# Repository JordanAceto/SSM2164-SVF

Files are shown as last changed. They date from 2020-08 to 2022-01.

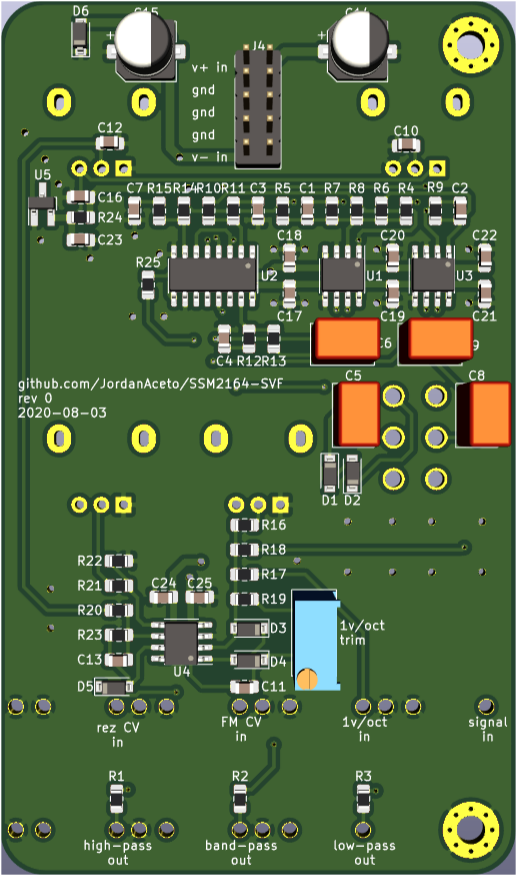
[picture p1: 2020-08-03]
main_pcb/pics/pcb_rear.png

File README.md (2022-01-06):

# SSI2164-SVF

State variable filter with audio and super-low-frequency modes.



---

## [SCHEMATIC](https://github.com/JordanAceto/SSI2164_SVF/blob/master/main_pcb/construction_docs/SSM2164_SVF_schematic.pdf)

---

Eurorack friendly pcb with mouting holes if flying wire construction is desired.

Range switch allows for super low frequency mode, which can be used as a sine wave LFO, or for creating "bouncy ADSRs", etc.

When used as a sine LFO, note that the band-pass and low-pass outputs are 90 &deg; out of phase with each other, and the high-pass and low-pass outputs are 180 &deg; out of phase. With a couple of inverters you can have 0 &deg;, 90 &deg;, 180 &deg;, and 270 &deg; outputs.

Note that the amplitude of the self oscillation is not perfectly flat across the frequency range, and may even peter out at very low frequencies. Additionally the sine wave appearing at the band-pass output is a little lower in amplitude than the other two. Don't expect amazing performance as a quadrature LFO, but I still find this to be a useful feature in a small system.

---

## Status of the project:

Task | Status |
---------|--------------|
Schematic capture | &#9745;
PCB layout | &#9745;
Test build | &#9745;
Safe to order boards| &#9745;

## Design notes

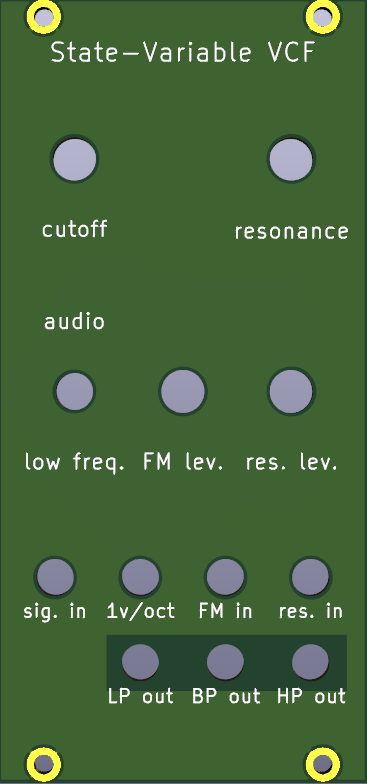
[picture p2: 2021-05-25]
front_panel/pics/front_panel.png

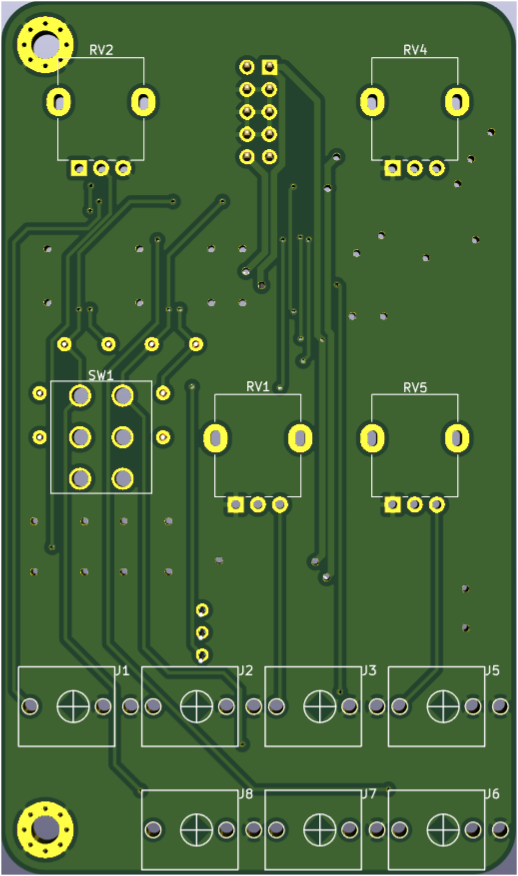
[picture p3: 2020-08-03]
main_pcb/pics/pcb_front.png

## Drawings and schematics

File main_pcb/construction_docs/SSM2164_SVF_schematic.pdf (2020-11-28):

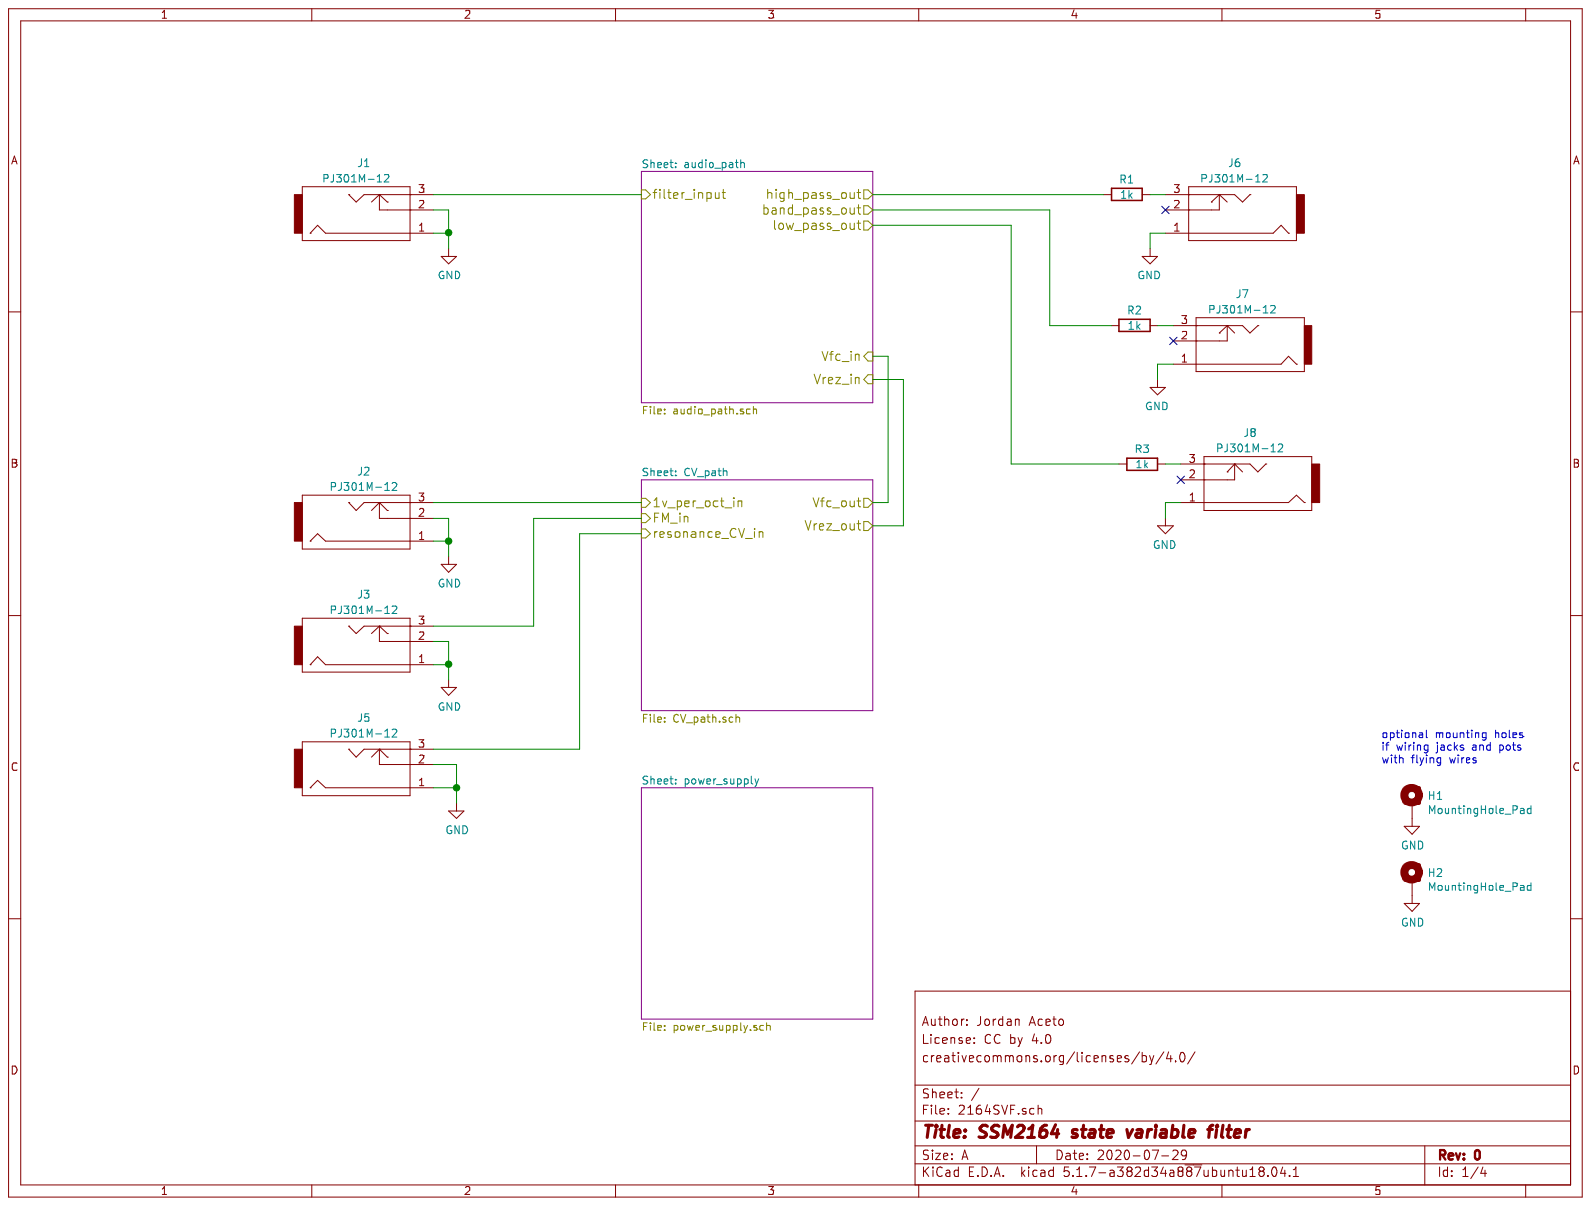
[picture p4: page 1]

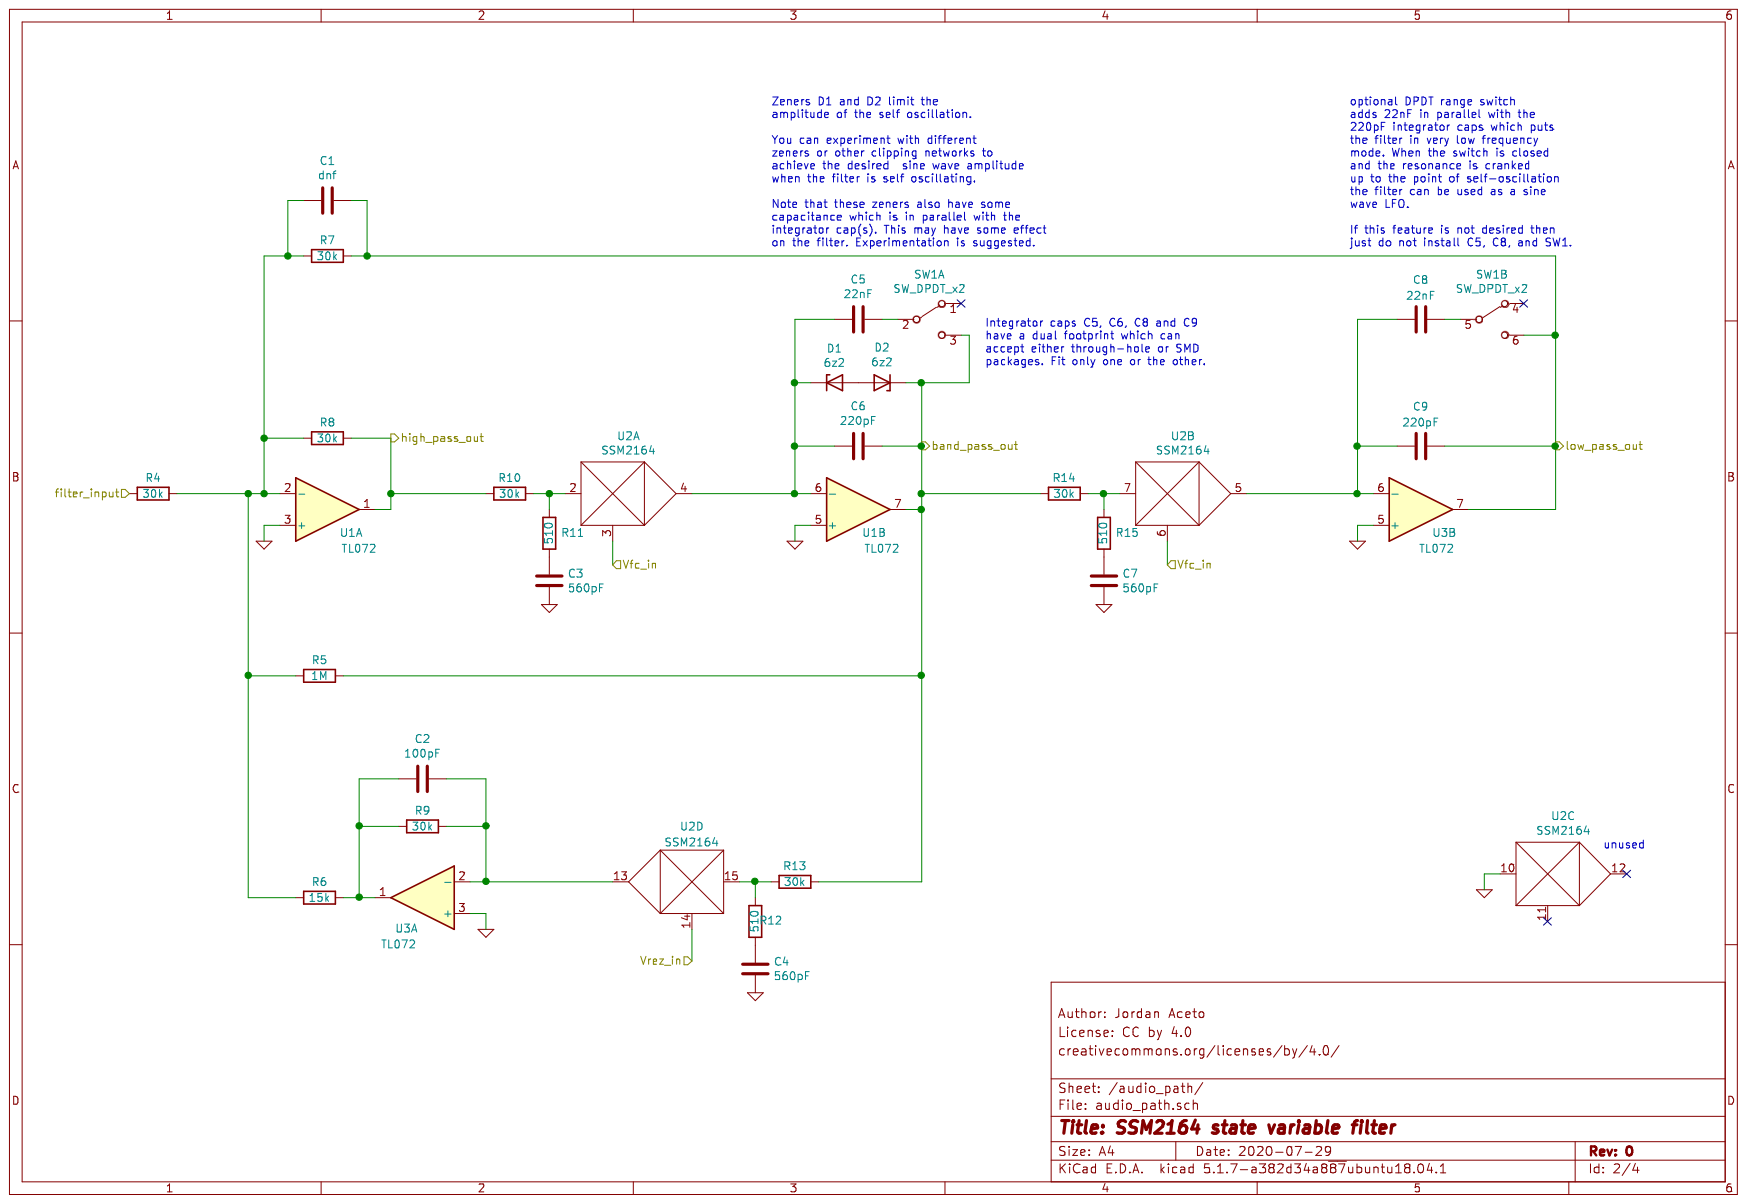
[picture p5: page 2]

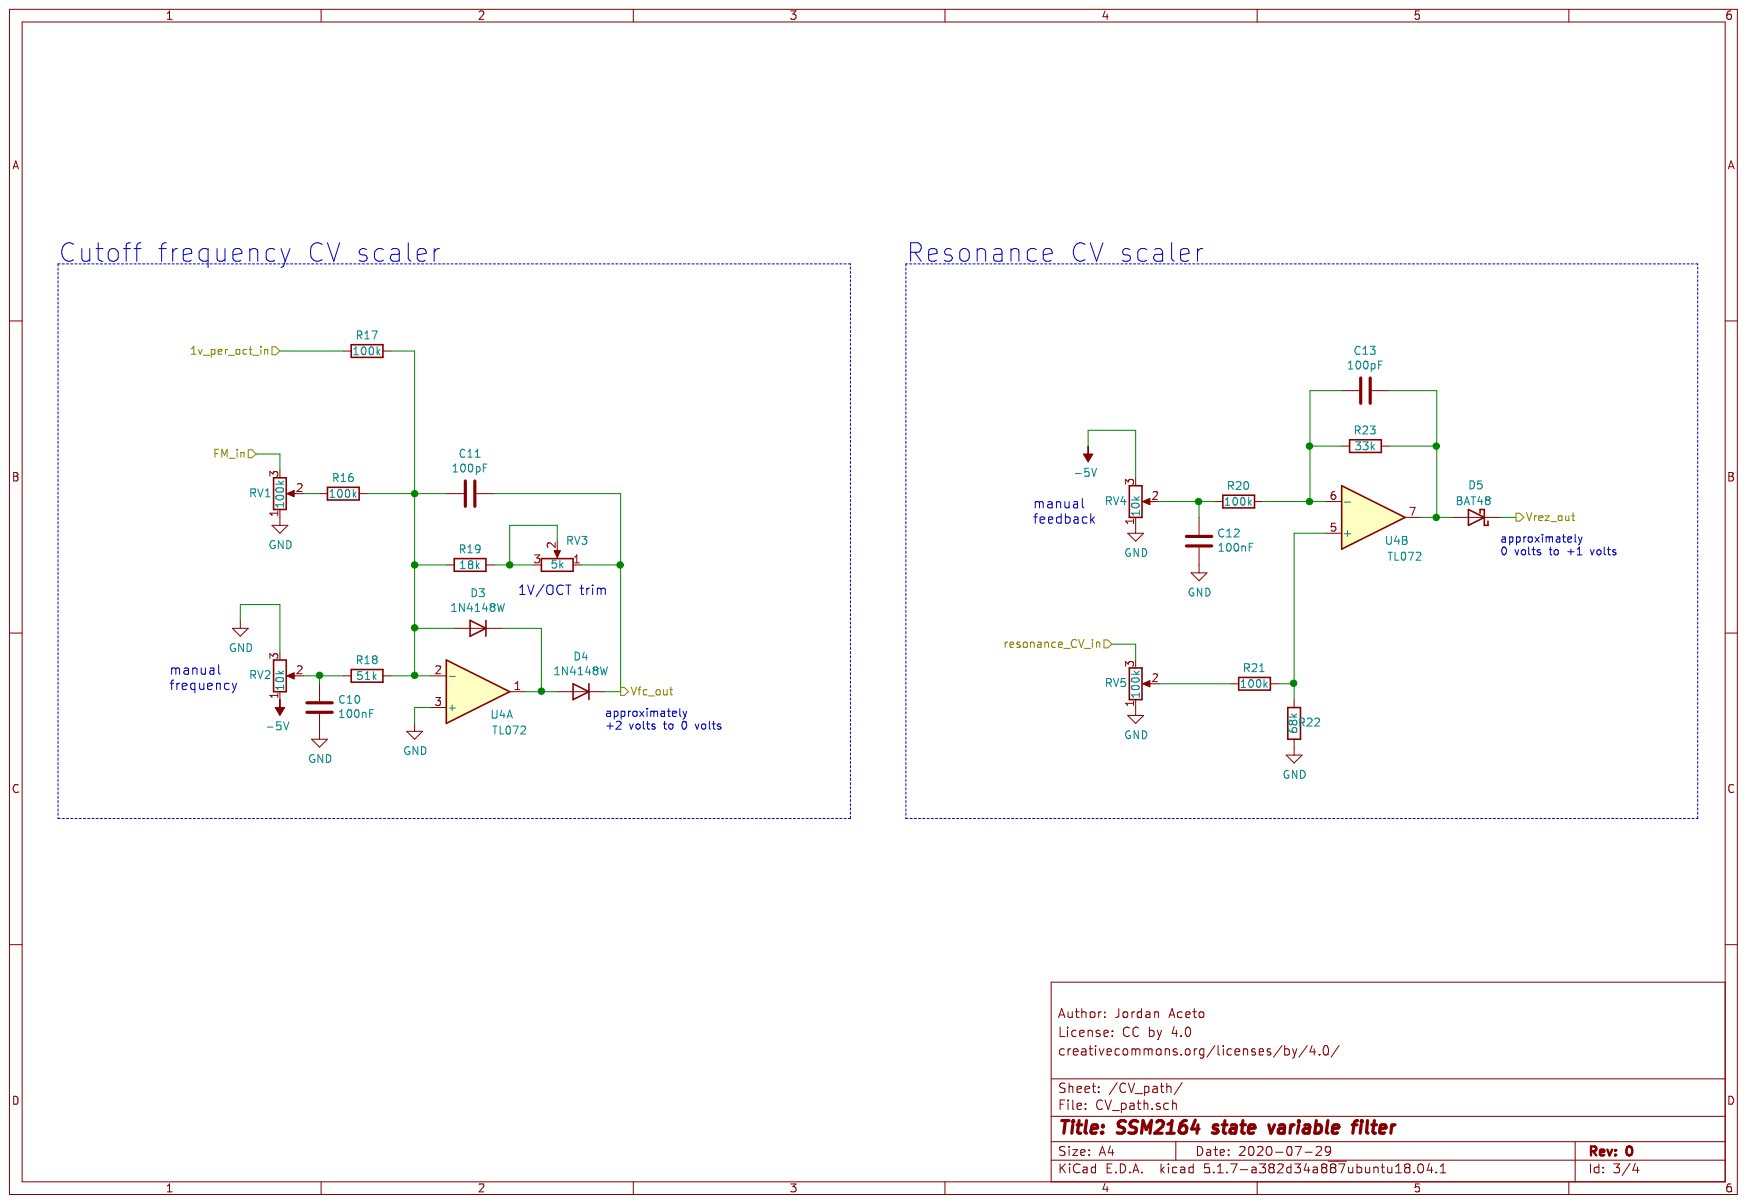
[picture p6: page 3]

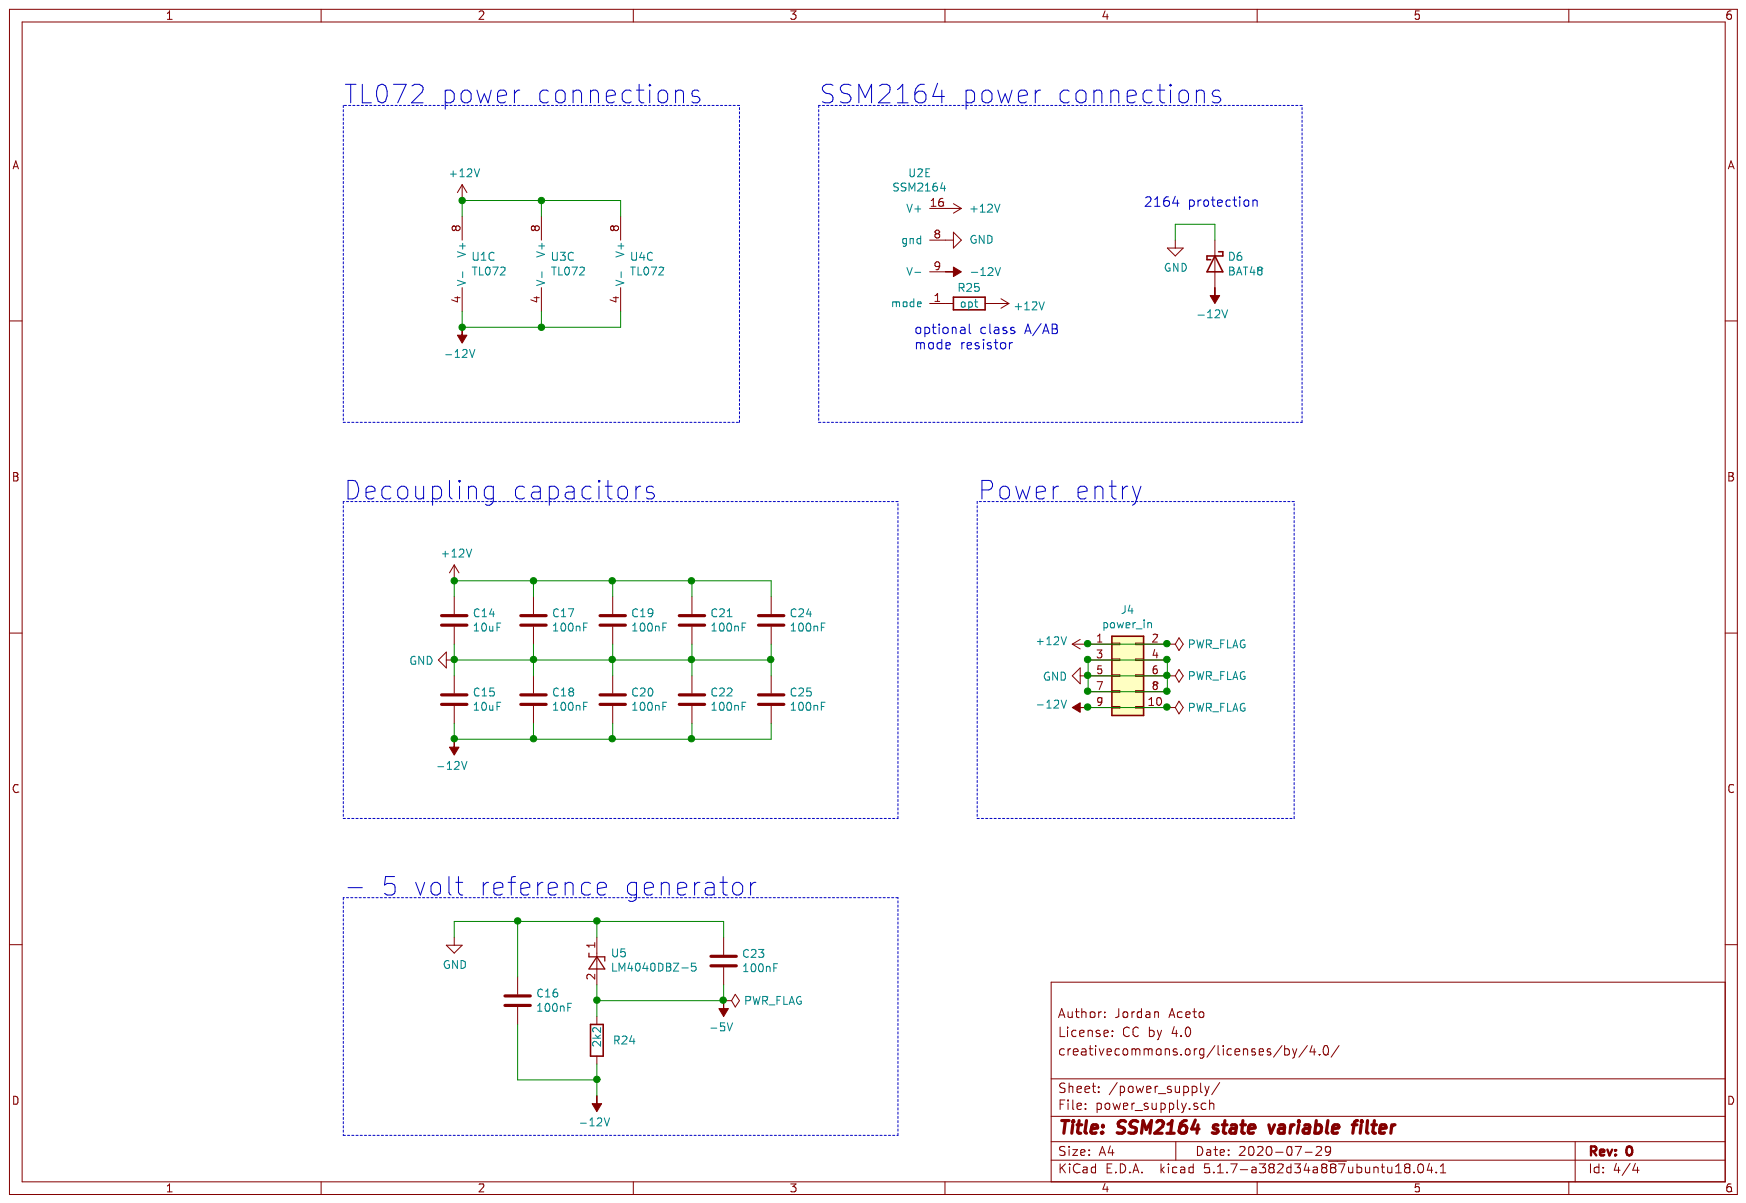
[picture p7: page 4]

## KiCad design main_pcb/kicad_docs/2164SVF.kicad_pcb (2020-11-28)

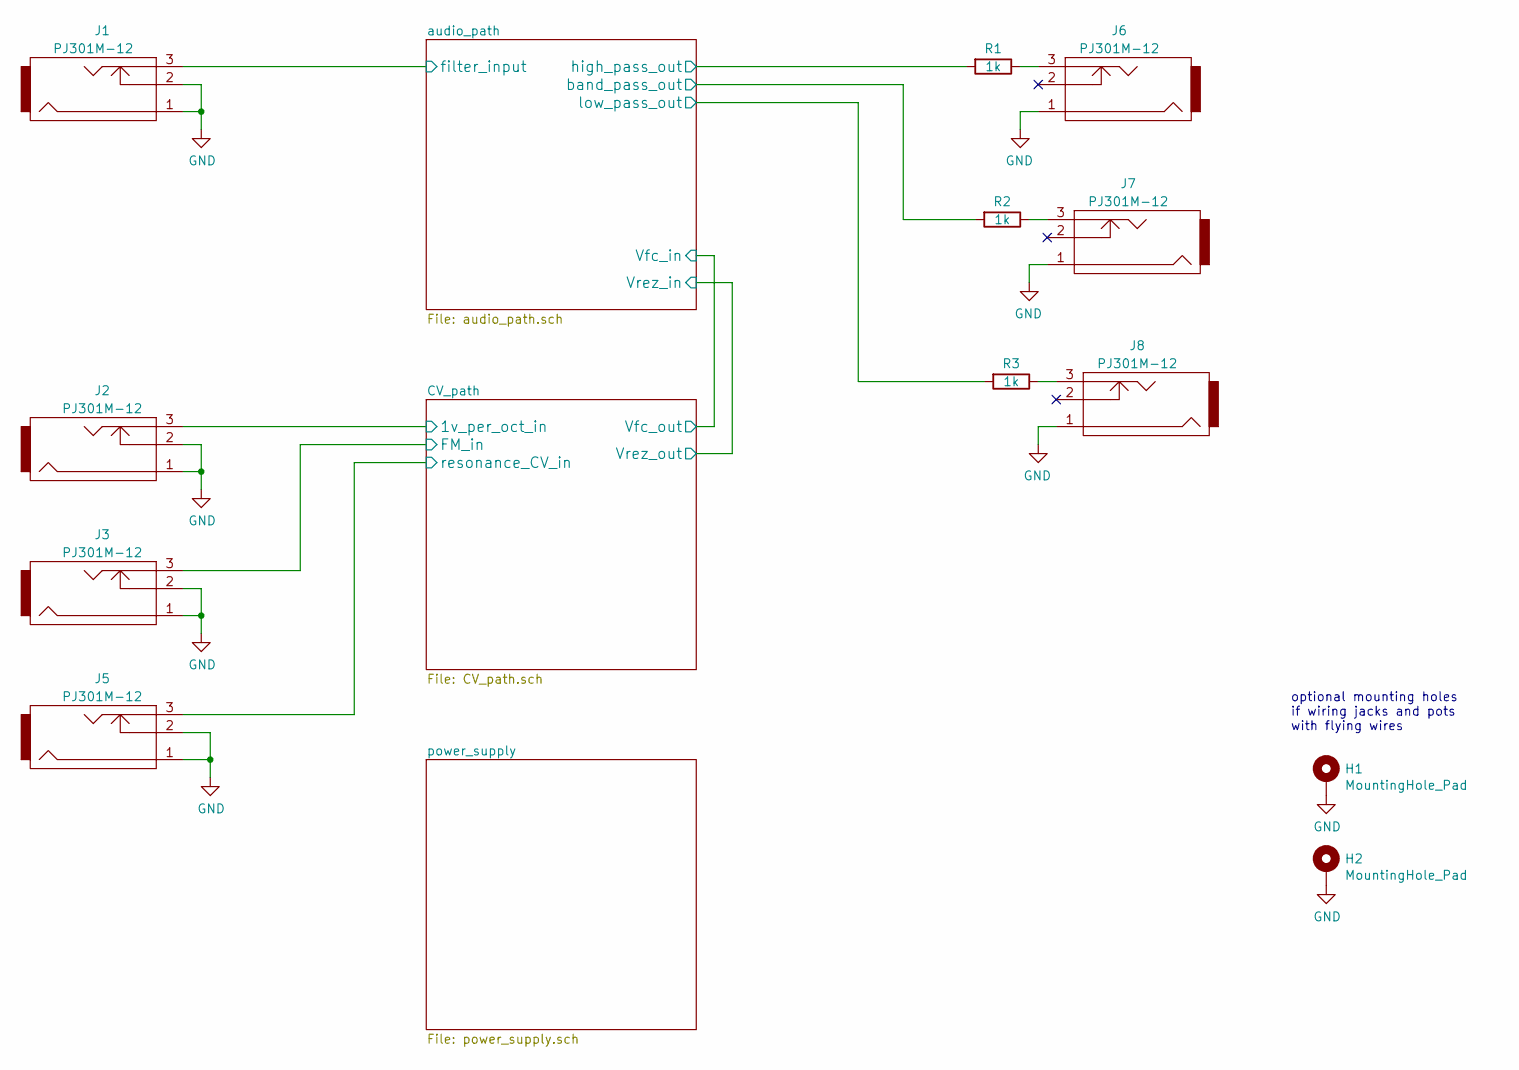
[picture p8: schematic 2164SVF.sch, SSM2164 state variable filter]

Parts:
H1, H2: MountingHole_Pad; MountingHole_3.2mm_M3_Pad_Via
J1, J2, J3, J5, J6, J7, J8: PJ301M-12
R1, R2, R3: 1k; R_0805_2012Metric_Pad1.15x1.40mm_HandSolder

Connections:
/CV_path/1v_per_oct_in: J2.3; also elsewhere on the board
/CV_path/FM_in: J3.3; also elsewhere on the board
/CV_path/resonance_CV_in: J5.3; also elsewhere on the board
/audio_path/band_pass_out: R2.2; also elsewhere on the board
/audio_path/filter_input: J1.3; also elsewhere on the board
/audio_path/high_pass_out: R1.2; also elsewhere on the board
/audio_path/low_pass_out: R3.2; also elsewhere on the board
GND: H1.1, H2.1, J1.1, J1.2, J2.1, J2.2, J3.1, J3.2, J5.1, J5.2, J6.1, J7.1, J8.1; also elsewhere on the board
unnamed: J6.3, R1.1
unnamed: J7.3, R2.1
unnamed: J8.3, R3.1

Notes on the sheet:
optional mounting holes if wiring jacks and pots with flying wires

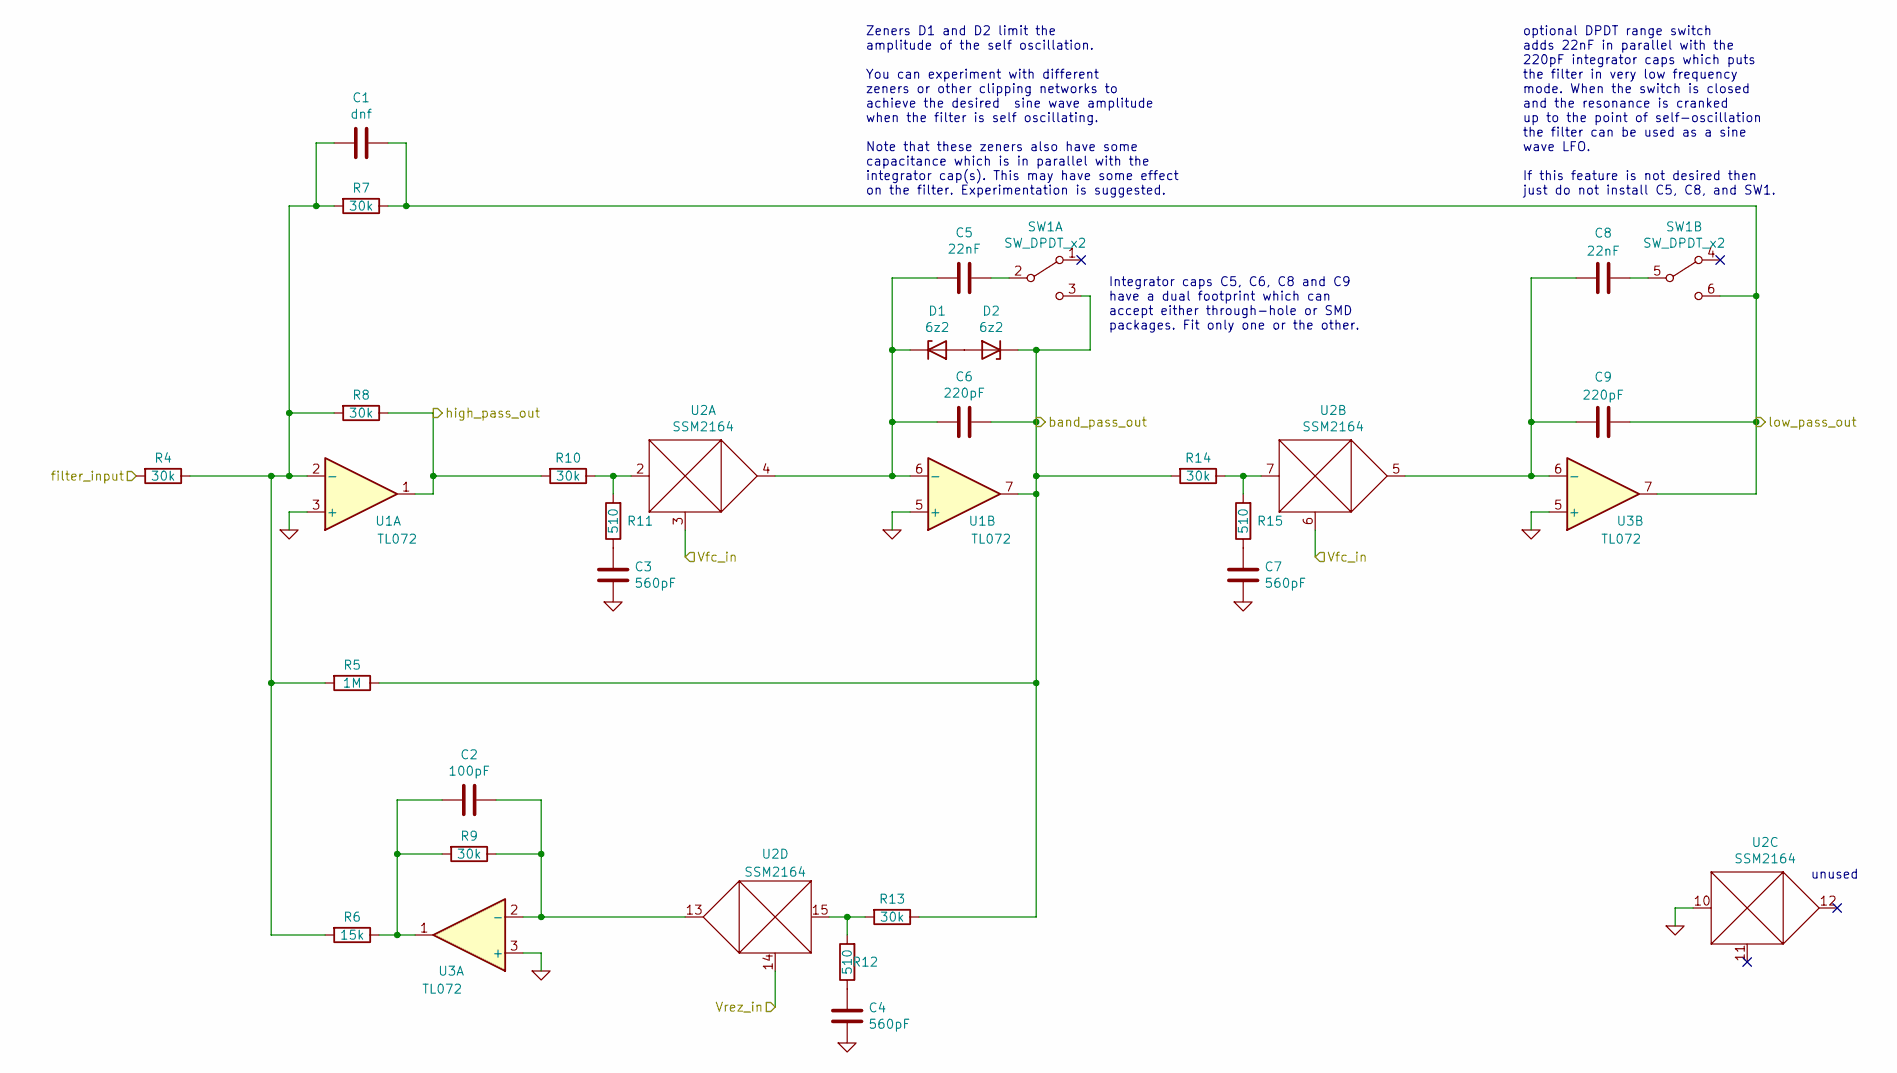
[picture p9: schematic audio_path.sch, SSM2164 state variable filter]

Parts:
C1: dnf; C_0805_2012Metric_Pad1.15x1.40mm_HandSolder
C2: 100pF; C_0805_2012Metric_Pad1.15x1.40mm_HandSolder
C3, C4, C7: 560pF; C_0805_2012Metric_Pad1.15x1.40mm_HandSolder
C5, C8: 22nF; timing_cap_dual_fp
C6, C9: 220pF; timing_cap_dual_fp
D1, D2: 6z2; D_SOD-123
R4, R7, R8, R9, R10, R13, R14: 30k; R_0805_2012Metric_Pad1.15x1.40mm_HandSolder
R5: 1M; R_0805_2012Metric_Pad1.15x1.40mm_HandSolder
R6: 15k; R_0805_2012Metric_Pad1.15x1.40mm_HandSolder
R11, R12, R15: 510; R_0805_2012Metric_Pad1.15x1.40mm_HandSolder
SW1: SW_DPDT_x2; DPDT_on_on
U1, U3: TL072; SOIC-8_3.9x4.9mm_P1.27mm
U2: SSM2164; SOIC-16_3.9x9.9mm_P1.27mm

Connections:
/audio_path/Vfc_in: U2.3, U2.6; also elsewhere on the board
/audio_path/Vrez_in: U2.14; also elsewhere on the board
/audio_path/band_pass_out: C6.1, D2.1 (K), R5.1, R13.1, R14.2, SW1.3 (C), U1.7; also elsewhere on the board
/audio_path/filter_input: R4.2; also elsewhere on the board
/audio_path/high_pass_out: R8.1, R10.2, U1.1; also elsewhere on the board
/audio_path/low_pass_out: C1.1, C9.1, R7.1, SW1.6 (C), U3.7; also elsewhere on the board
GND: C3.2, C4.2, C7.2, U1.3 (+), U1.5 (+), U2.10, U3.3 (+), U3.5 (+); also elsewhere on the board
unnamed: C1.2, R4.1, R5.2, R6.2, R7.2, R8.2, U1.2 (-)
unnamed: C2.1, R9.1, U2.13, U3.2 (-)
unnamed: C2.2, R6.1, R9.2, U3.1
unnamed: C3.1, R11.1
unnamed: C4.1, R12.1
unnamed: C5.1, SW1.2 (B)
unnamed: C5.2, C6.2, D1.1 (K), U1.6 (-), U2.4
unnamed: C7.1, R15.1
unnamed: C8.1, SW1.5 (B)
unnamed: C8.2, C9.2, U2.5, U3.6 (-)
unnamed: D1.2 (A), D2.2 (A)
unnamed: R10.1, R11.2, U2.2
unnamed: R12.2, R13.2, U2.15
unnamed: R14.1, R15.2, U2.7

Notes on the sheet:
optional DPDT range switch adds 22nF in parallel with the 220pF integrator caps which puts the filter in very low frequency mode. When the switch is closed and the resonance is cranked up to the point of self-oscillation the filter can be used as a sine wave LFO. If this feature is not desired then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
unused
Integrator caps C5, C6, C8 and C9 have a dual footprint which can accept either through-hole or SMD packages. Fit only one or the other.
Zeners D1 and D2 limit the amplitude of the self oscillation. You can experiment with different zeners or other clipping networks to achieve the desired sine wave amplitude when the filter is self oscillating. Note that these zeners also have some capacitance which is in parallel with the integrato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

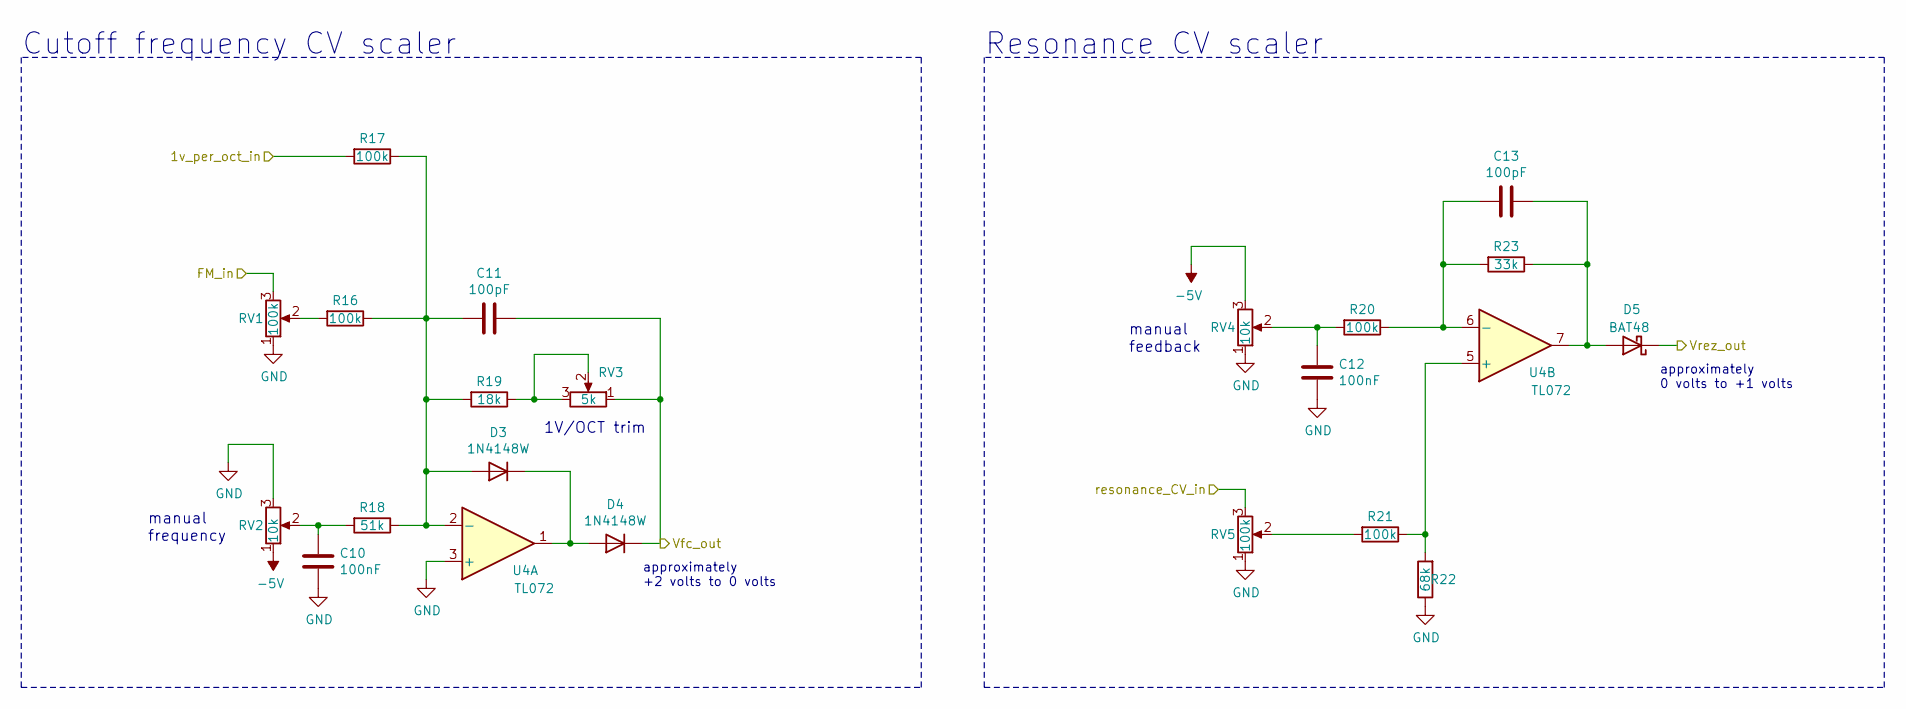
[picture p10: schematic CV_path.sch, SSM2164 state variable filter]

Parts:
C10, C12: 100nF; C_0805_2012Metric_Pad1.15x1.40mm_HandSolder
C11, C13: 100pF; C_0805_2012Metric_Pad1.15x1.40mm_HandSolder
D3, D4: 1N4148W; D_SOD-123
D5: BAT48; D_SOD-123
R16, R17, R20, R21: 100k; R_0805_2012Metric_Pad1.15x1.40mm_HandSolder
R18: 51k; R_0805_2012Metric_Pad1.15x1.40mm_HandSolder
R19: 18k; R_0805_2012Metric_Pad1.15x1.40mm_HandSolder
R22: 68k; R_0805_2012Metric_Pad1.15x1.40mm_HandSolder
R23: 33k; R_0805_2012Metric_Pad1.15x1.40mm_HandSolder
RV1, RV5: 100k; Potentiometer_Alpha_RD901F-40-00D_Single_Vertical
RV2, RV4: 10k; Potentiometer_Alpha_RD901F-40-00D_Single_Vertical
RV3: 5k; Potentiometer_Bourns_3296W_Vertical
U4: TL072; SOIC-8_3.9x4.9mm_P1.27mm

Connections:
-5V: RV2.1, RV4.3; also elsewhere on the board
/CV_path/1v_per_oct_in: R17.2; also elsewhere on the board
/CV_path/FM_in: RV1.3; also elsewhere on the board
/CV_path/resonance_CV_in: RV5.3; also elsewhere on the board
/audio_path/Vfc_in: C11.1, D4.1 (K), RV3.1; also elsewhere on the board
/audio_path/Vrez_in: D5.1 (K); also elsewhere on the board
GND: C10.1, C12.1, R22.1, RV1.1, RV2.3, RV4.1, RV5.1, U4.3 (+); also elsewhere on the board
unnamed: C10.2, R18.2, RV2.2
unnamed: C11.2, D3.2 (A), R16.1, R17.1, R18.1, R19.2, U4.2 (-)
unnamed: C12.2, R20.2, RV4.2
unnamed: C13.1, D5.2 (A), R23.1, U4.7
unnamed: C13.2, R20.1, R23.2, U4.6 (-)
unnamed: D3.1 (K), D4.2 (A), U4.1
unnamed: R16.2, RV1.2
unnamed: R19.1, RV3.2, RV3.3
unnamed: R21.1, R22.2, U4.5 (+)
unnamed: R21.2, RV5.2

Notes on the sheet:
1V/OCT trim
manual frequency
manual feedback
Cutoff frequency CV scaler
Resonance CV scaler
approximately 0 volts to +1 volts
approximately +2 volts to 0 volts

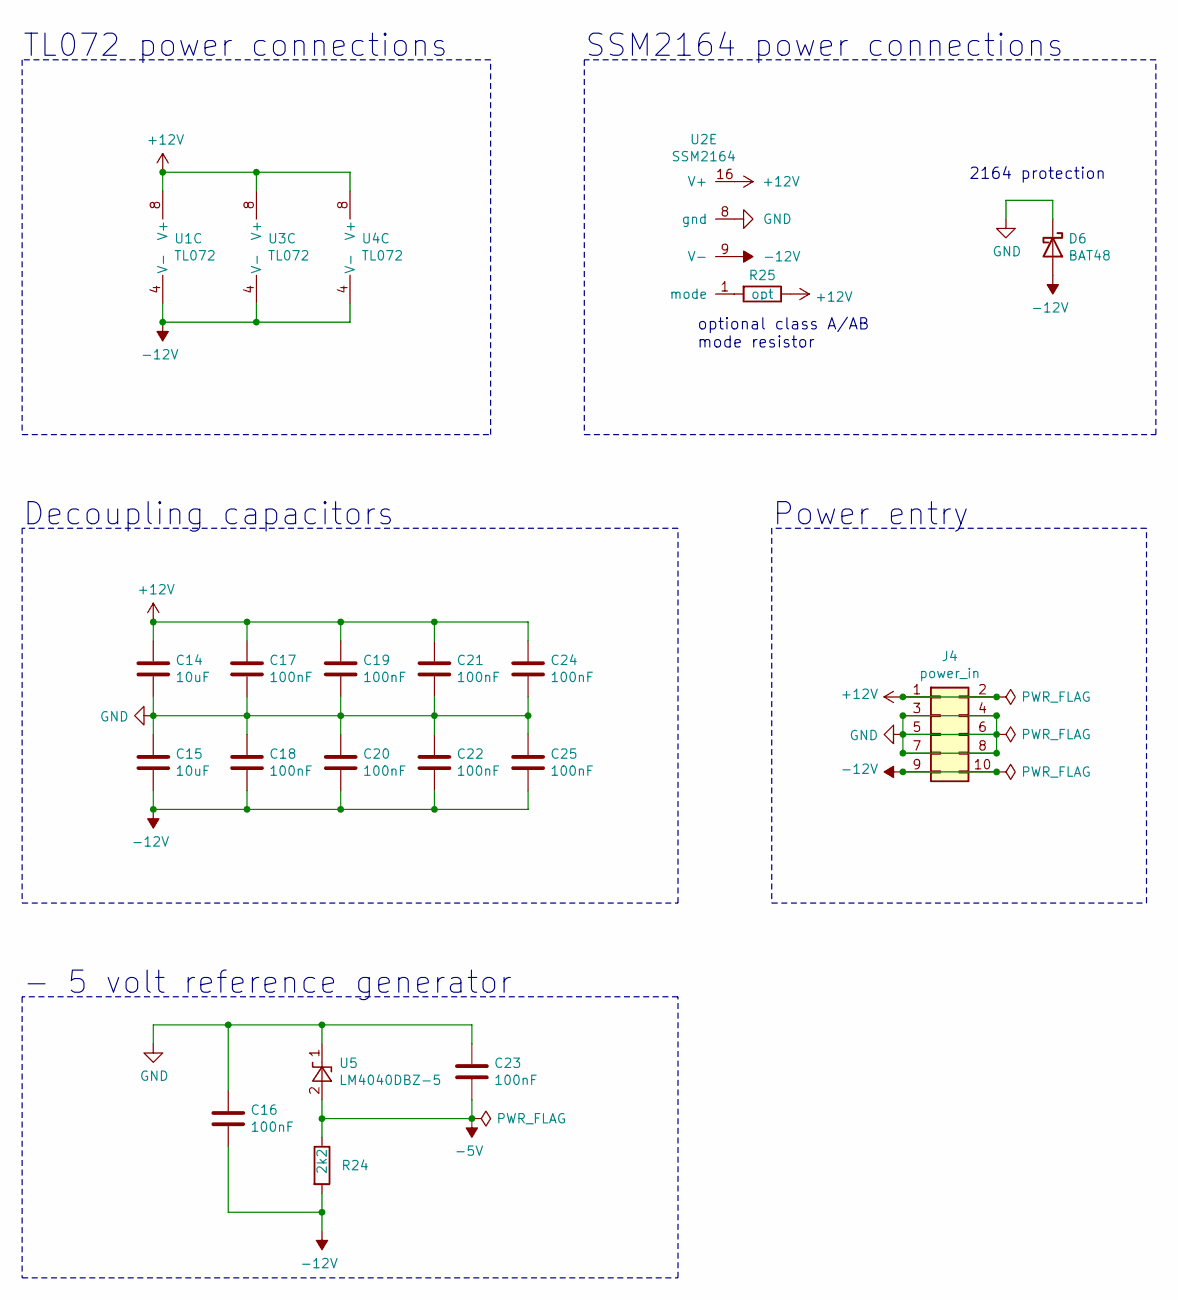
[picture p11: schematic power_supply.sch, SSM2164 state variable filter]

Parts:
C14, C15: 10uF; CP_Elec_6.3x5.4_Nichicon
C16, C17, C18, C19, C20, C21, C22, C23, C24, C25: 100nF; C_0805_2012Metric_Pad1.15x1.40mm_HandSolder
D6: BAT48; D_SOD-123
J4: power_in; PinHeader_2x05_P2.54mm_Vertical
R24: 2k2; R_0805_2012Metric_Pad1.15x1.40mm_HandSolder
R25: opt; R_0805_2012Metric_Pad1.15x1.40mm_HandSolder
U1, U3, U4: TL072; SOIC-8_3.9x4.9mm_P1.27mm
U2: SSM2164; SOIC-16_3.9x9.9mm_P1.27mm
U5: LM4040DBZ-5; SOT-23_Handsoldering

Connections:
+12V: C14.1, C17.1, C19.1, C21.1, C24.1, J4.1, J4.2, R25.1, U1.8 (V+), U2.16 (V+), U3.8 (V+), U4.8 (V+)
-5V: C23.2, R24.1, U5.2 (A); also elsewhere on the board
-12V: C15.2, C16.2, C18.2, C20.2, C22.2, C25.2, D6.2 (A), J4.9, J4.10, R24.2, U1.4 (V-), U2.9 (V-), U3.4 (V-), U4.4 (V-)
GND: C14.2, C15.1, C16.1, C17.2, C18.1, C19.2, C20.1, C21.2, C22.1, C23.1, C24.2, C25.1, D6.1 (K), J4.3, J4.4, J4.5, J4.6, J4.7, J4.8, U2.8 (gnd), U5.1 (K); also elsewhere on the board
unnamed: R25.2, U2.1 (mode)

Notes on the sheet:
2164 protection
optional class A/AB mode resistor
TL072 power connections
SSM2164 power connections
Decoupling capacitors
Power entry
- 5 volt reference generator

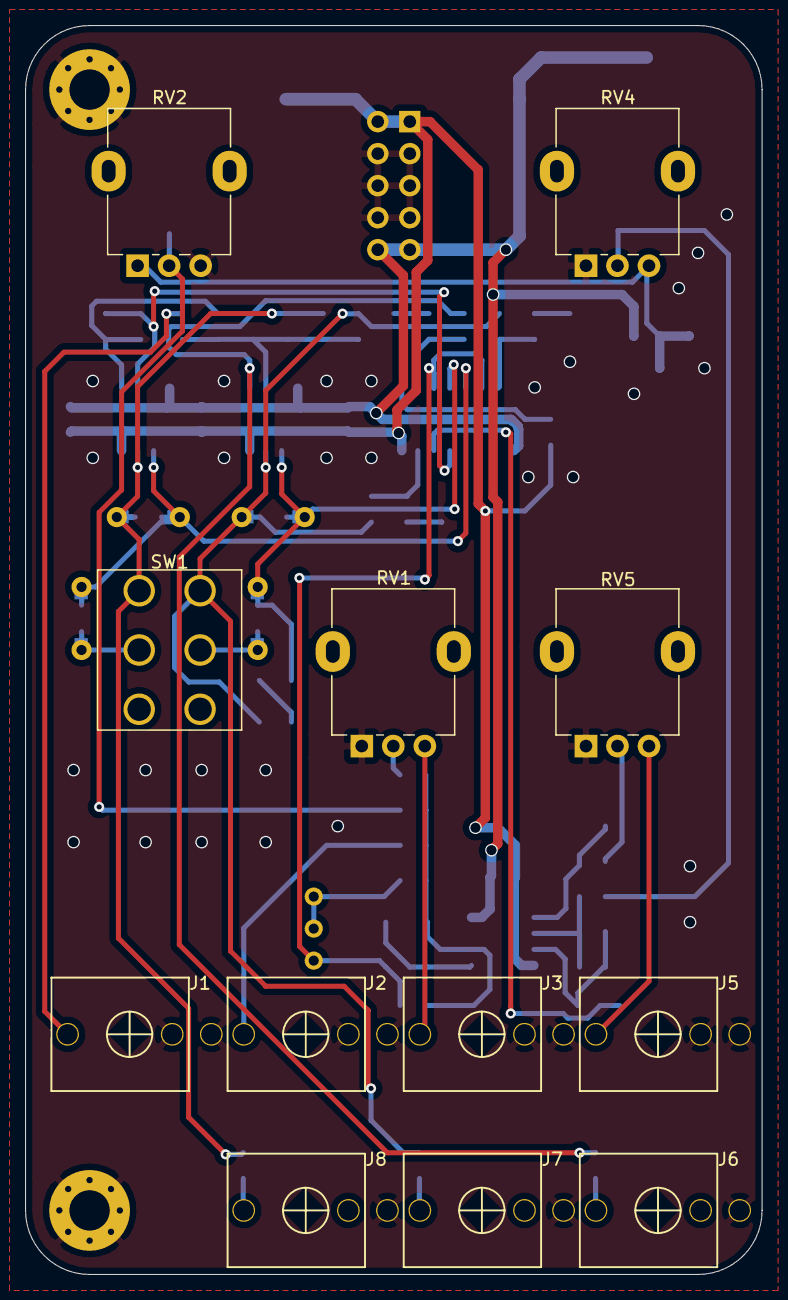
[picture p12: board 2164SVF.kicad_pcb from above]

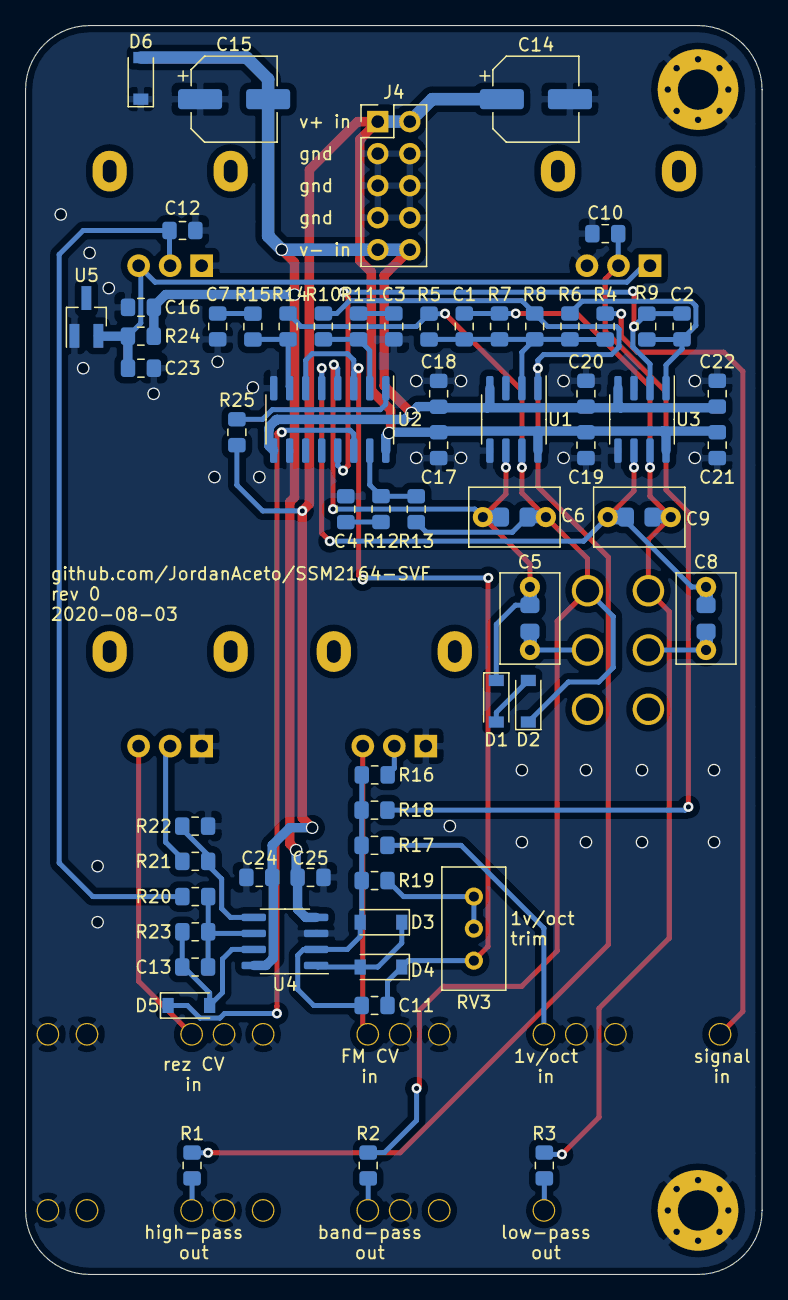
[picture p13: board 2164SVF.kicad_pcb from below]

Board: 2 copper layers, 58.4 x 99.1 mm, 77 parts (63 on the bottom side), 41 nets.

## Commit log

2018-09-01 add PDF of schematic
2020-07-31 big change, tidy schemo, update repo structure
    [2164SVF.kicad_pcb, 2164SVF.sch, CV_path.sch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]
2020-07-31 fix problem where jacks were all upside-down
    [2164SVF.sch]
2020-08-03 first rev pcb layout
    [2164SVF-B_Cu.gbr, 2164SVF-B_Mask.gbr, 2164SVF-B_Paste.gbr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]
2020-08-03 update schematic
2020-08-03 generate interactive BOM
2020-08-03 add some rendered pcb pics
2020-11-28 built and tested, minor component changes
    [2164SVF-B_Cu.gbr, 2164SVF-B_Mask.gbr, 2164SVF-B_Paste.gbr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]
2021-05-25 add front panel, reorganize repo
    [2164SVF-B_Cu.gbr, 2164SVF-B_Mask.gbr, 2164SVF-B_SilkS.gbr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]
2022-01-06 front panel gerbers
    [front_panel-B_Cu.gbl, front_panel-B_Mask.gbs, front_panel-B_SilkS.gbo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]
2022-01-06 add link to schematic

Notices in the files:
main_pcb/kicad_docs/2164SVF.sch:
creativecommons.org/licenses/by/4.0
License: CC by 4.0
